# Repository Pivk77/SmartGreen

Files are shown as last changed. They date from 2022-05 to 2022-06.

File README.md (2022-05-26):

# SmartGreen

Smart watering project for your garden. It uses multiple sensors such as ultrasonic depth measurement of your watering tank, humidity sensors, and online weather forecast.

## Usage/Examples

In this repository you are provided with in-detailed schematics of the PCB-board for diy purposes. In the future you might be able to buy the PCB.

The device is meant to be used with [ESPHOME](https://esphome.io/) installed onto and work in conjunction with [HomeAssistant](https://www.home-assistant.io/).

The device uses 12VDC power input. There are 5 230V/16A relays installed onto it so you can connect devices up to 230V (could be less). I've used them as switches for garden pumps and electromagnetic valves.

It also has the built in connector for [SR04M](https://www.google.com/search?q=sr04m) ultrasonic sensor i've used to detect the level of water in a tank.
## Authors

- [@Pivk77](https://github.com/Pivk77)

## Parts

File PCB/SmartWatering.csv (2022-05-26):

Source: | C:\Users\matev\Desktop\SmartWatering\SmartWatering\SmartWatering.kicad_sch
Date: | 24. 05. 2022 16:49:50
Tool: | Eeschema (6.0.5)
Generator: | C:\Program Files\KiCad\6.0\bin\scripting\plugins/bom_csv_grouped_by_value.py
Component Count: | 18
Individual Components:
Item | Qty | Reference(s) | Value | LibPart | Footprint | Datasheet | Spice_Netlist_Enabled | Spice_Primitive
 |  | C1 | 100uF | Device:C_Polarized | Capacitor_THT:CP_Radial_D6.3mm_P2.50mm | ~
 |  | C2 | 10uF | Device:C | Capacitor_SMD:C_0805_2012Metric_Pad1.18x1.45mm_HandSolder | ~
 |  | C3 | 10uF | Device:C | Capacitor_SMD:C_0805_2012Metric_Pad1.18x1.45mm_HandSolder | ~
 |  | C4 | 10uF | Device:C |  | ~
 |  | C5 | 10uF | Device:C |  | ~
 |  | D1 | DIODE | Simulation_SPICE:DIODE | Diode_SMD:D_SMA_Handsoldering | ~ | Y | D
 |  | D2 | LED | Device:LED | LED_SMD:LED_0805_2012Metric_Pad1.15x1.40mm_HandSolder | ~
 |  | J1 | Power_Screw_Terminal | Connector:Screw_Terminal_01x02 | TerminalBlock_Phoenix:TerminalBlock_Phoenix_MPT-0,5-2-2.54_1x02_P2.54mm_Horizontal | ~
 |  | R1 | 12k | Device:R | Resistor_SMD:R_0805_2012Metric_Pad1.20x1.40mm_HandSolder | ~
 |  | R2 | 1k | Device:R | Resistor_SMD:R_0805_2012Metric_Pad1.20x1.40mm_HandSolder | ~
 |  | R3 | 12k | Device:R | Resistor_SMD:R_0805_2012Metric_Pad1.20x1.40mm_HandSolder | ~
 |  | R4 | 12k | Device:R | Resistor_SMD:R_0805_2012Metric_Pad1.20x1.40mm_HandSolder | ~
 |  | R5 | 1k | Device:R | Resistor_SMD:R_0805_2012Metric_Pad1.20x1.40mm_HandSolder | ~
 |  | S1 | Flash_button | Switch:SW_Push |  | ~
 |  | S2 | Reset_button | Switch:SW_Push |  | ~
 |  | U1 | ESP32-WROOM | ESP32-footprints-Shem-Lib:ESP32-WROOM | ESP32-footprints-Lib:ESP32-WROOM
 |  | U2 | L7805 | Regulator_Linear:L7805 | Package_TO_SOT_SMD:TO-263-3_TabPin2 | http://www.st.com/content/ccc/resource/technical/document/datasheet/41/4f/b3/b0/12/d4/47/88/CD00000444.pdf/files/CD00000444.pdf/jcr:content/translations/en.CD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
 |  | U3 | LM3940 | Regulator_Linear:L7805 | Package_TO_SOT_SMD:TO-263-3_TabPin2 | http://www.st.com/content/ccc/resource/technical/document/datasheet/41/4f/b3/b0/12/d4/47/88/CD00000444.pdf/files/CD00000444.pdf/jcr:content/translations/en.CD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
Collated Components:
Item | Qty | Reference(s) | Value | LibPart | Footprint | Datasheet | Spice_Netlist_Enabled | Spice_Primitive
1 | 1 | C1 | 100uF | Device:C_Polarized | Capacitor_THT:CP_Radial_D6.3mm_P2.50mm | ~
2 | 2 | C2, C3 | 10uF | Device:C | Capacitor_SMD:C_0805_2012Metric_Pad1.18x1.45mm_HandSolder | ~
3 | 2 | C4, C5 | 10uF | Device:C |  | ~
4 | 1 | D1 | DIODE | Simulation_SPICE:DIODE | Diode_SMD:D_SMA_Handsoldering | ~ | Y | D
5 | 1 | D2 | LED | Device:LED | LED_SMD:LED_0805_2012Metric_Pad1.15x1.40mm_HandSolder | ~
6 | 1 | J1 | Power_Screw_Terminal | Connector:Screw_Terminal_01x02 | TerminalBlock_Phoenix:TerminalBlock_Phoenix_MPT-0,5-2-2.54_1x02_P2.54mm_Horizontal | ~
7 | 3 | R1, R3, R4 | 12k | Device:R | Resistor_SMD:R_0805_2012Metric_Pad1.20x1.40mm_HandSolder | ~
8 | 2 | R2, R5 | 1k | Device:R | Resistor_SMD:R_0805_2012Metric_Pad1.20x1.40mm_HandSolder | ~
9 | 1 | S1 | Flash_button | Switch:SW_Push |  | ~
10 | 1 | S2 | Reset_button | Switch:SW_Push |  | ~
11 | 1 | U1 | ESP32-WROOM | ESP32-footprints-Shem-Lib:ESP32-WROOM | ESP32-footprints-Lib:ESP32-WROOM
12 | 1 | U2 | L7805 | Regulator_Linear:L7805 | Package_TO_SOT_SMD:TO-263-3_TabPin2 | http://www.st.com/content/ccc/resource/technical/document/datasheet/41/4f/b3/b0/12/d4/47/88/CD00000444.pdf/files/CD00000444.pdf/jcr:content/translations/en.CD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
13 | 1 | U3 | LM3940 | Regulator_Linear:L7805 | Package_TO_SOT_SMD:TO-263-3_TabPin2 | http://www.st.com/content/ccc/resource/technical/document/datasheet/41/4f/b3/b0/12/d4/47/88/CD00000444.pdf/files/CD00000444.pdf/jcr:content/translations/en.CD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

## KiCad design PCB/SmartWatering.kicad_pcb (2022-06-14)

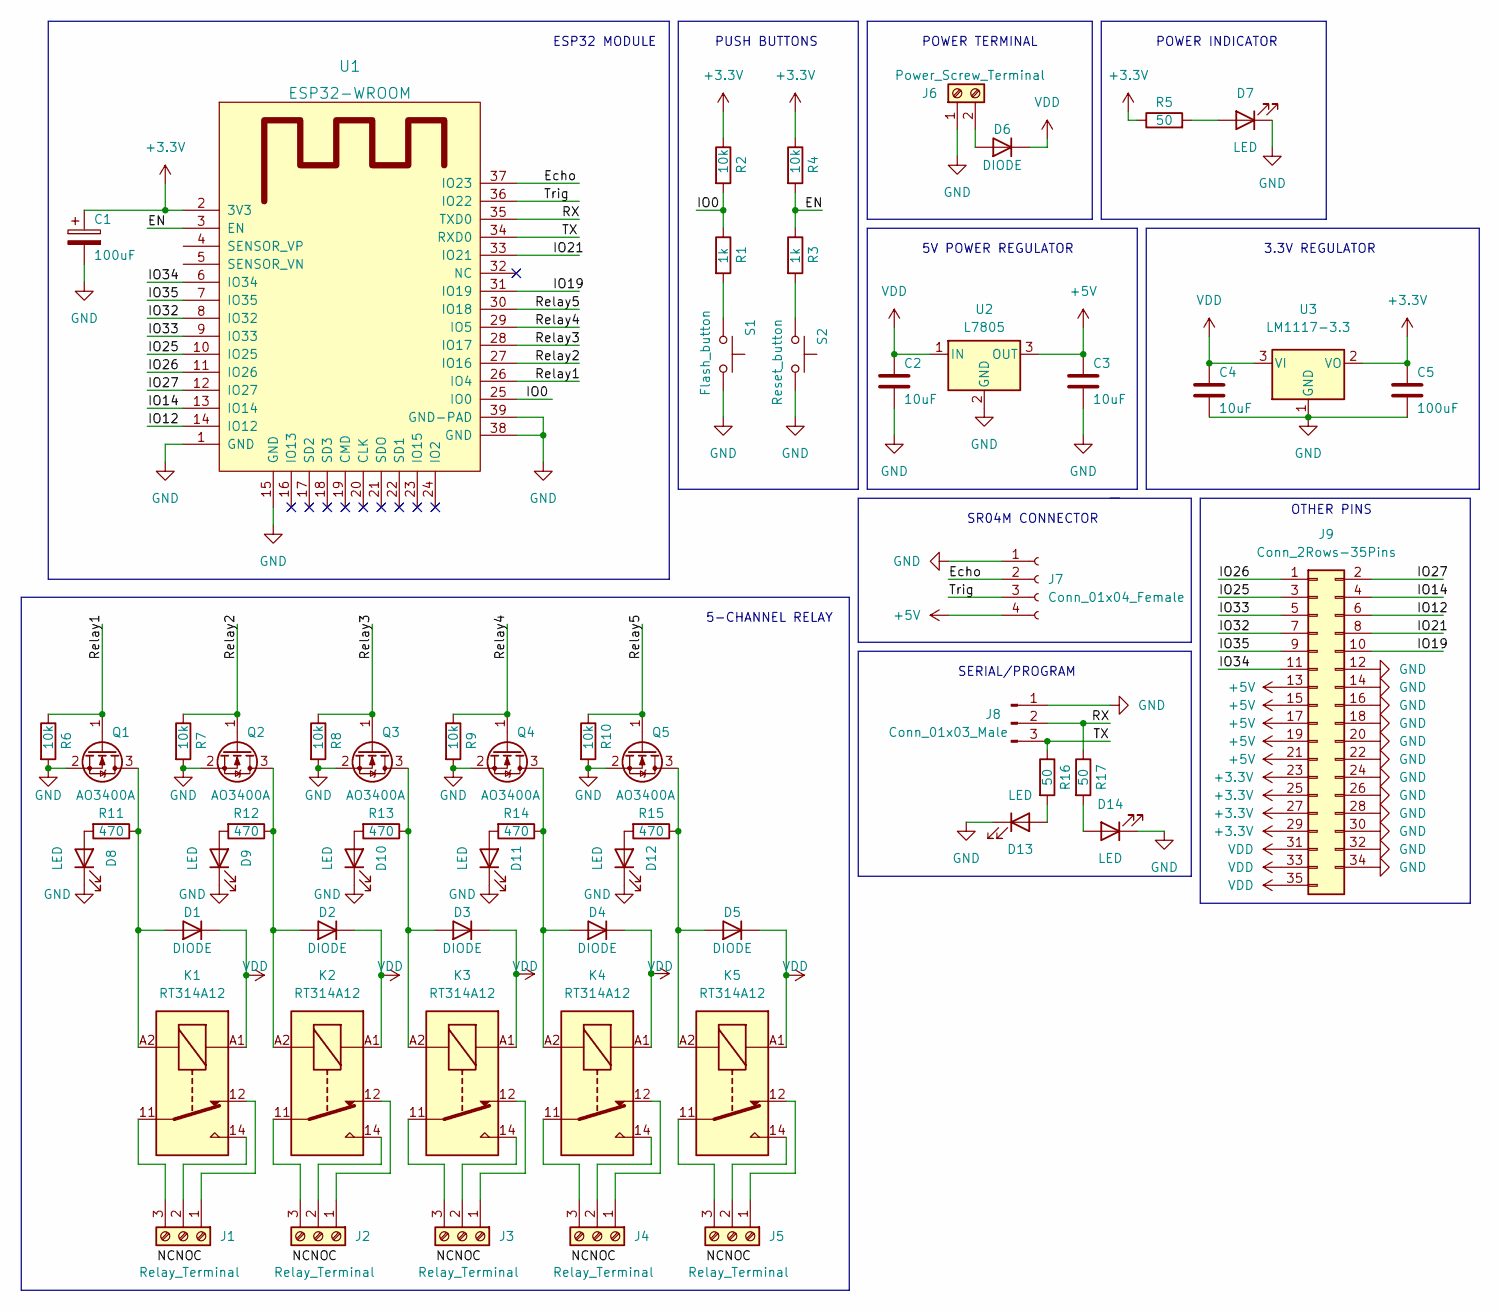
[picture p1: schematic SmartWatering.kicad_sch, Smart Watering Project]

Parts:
C1: 100uF; CP_Radial_D6.3mm_P2.50mm
C2, C3, C4: 10uF; C_0805_2012Metric_Pad1.18x1.45mm_HandSolder
C5: 100uF; C_0805_2012Metric_Pad1.18x1.45mm_HandSolder
D1, D2, D3, D4, D5, D6: DIODE; D_SMA_Handsoldering
D7, D8, D9, D10, D11, D12, D13, D14: LED; LED_0805_2012Metric_Pad1.15x1.40mm_HandSolder
J1, J2, J3, J4, J5: Relay_Terminal; TerminalBlock_Phoenix_MPT-0,5-3-2.54_1x03_P2.54mm_Horizontal
J6: Power_Screw_Terminal; TerminalBlock_Phoenix_MPT-0,5-2-2.54_1x02_P2.54mm_Horizontal
J7: Conn_01x04_Female; PinHeader_1x04_P2.54mm_Vertical
J8: Conn_01x03_Male; PinHeader_1x03_P2.54mm_Vertical
J9: Conn_2Rows-35Pins; PinHeader_2x18_P2.54mm_Vertical
K1, K2, K3, K4, K5: RT314A12; Relay_SPDT_Schrack-RT1-16A-FormC_RM5mm
Q1, Q2, Q3, Q4, Q5: AO3400A; SOT-23
R1, R3: 1k; R_0805_2012Metric_Pad1.20x1.40mm_HandSolder
R2, R4, R6, R7, R8, R9, R10: 10k; R_0805_2012Metric_Pad1.20x1.40mm_HandSolder
R5, R16, R17: 50; R_0805_2012Metric_Pad1.20x1.40mm_HandSolder
R11, R12, R13, R14, R15: 470; R_0805_2012Metric_Pad1.20x1.40mm_HandSolder
S1: Flash_button; SW_SPST_SKQG_WithoutStem
S2: Reset_button; SW_SPST_SKQG_WithoutStem
U1: ESP32-WROOM
U2: L7805; SOT-223-3_TabPin2
U3: LM1117-3.3; SOT-223-3_TabPin2

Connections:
+3V3: C1.1, C5.1, J9.23, J9.25, J9.27, J9.29, R2.1, R4.1, R5.1, U1.2 (3V3), U3.2 (VO)
+5V: C3.1, J7.4, J9.13, J9.15, J9.17, J9.19, J9.21, U2.3 (OUT)
/EN: R3.1, R4.2, U1.3 (EN)
/Echo: J7.2, U1.37 (IO23)
/IO0: R1.1, R2.2, U1.25 (IO0)
/IO12: J9.6, U1.14 (IO12)
/IO14: J9.4, U1.13 (IO14)
/IO19: J9.10, U1.31 (IO19)
/IO21: J9.8, U1.33 (IO21)
/IO25: J9.3, U1.10 (IO25)
/IO26: J9.1, U1.11 (IO26)
/IO27: J9.2, U1.12 (IO27)
/IO32: J9.7, U1.8 (IO32)
/IO33: J9.5, U1.9 (IO33)
/IO34: J9.11, U1.6 (IO34)
/IO35: J9.9, U1.7 (IO35)
/RX: J8.2, R17.1, U1.35 (TXD0)
/Relay1: Q1.1 (G), R6.1, U1.26 (IO4)
/Relay2: Q2.1 (G), R7.1, U1.27 (IO16)
/Relay3: Q3.1 (G), R8.1, U1.28 (IO17)
/Relay4: Q4.1 (G), R9.1, U1.29 (IO5)
/Relay5: Q5.1 (G), R10.1, U1.30 (IO18)
/TX: J8.3, R16.1, U1.34 (RXD0)
/Trig: J7.3, U1.36 (IO22)
GND: C1.2, C2.2, C3.2, C4.2, C5.2, D7.1 (K), D8.1 (K), D9.1 (K), D10.1 (K), D11.1 (K), D12.1 (K), D13.1 (K), D14.1 (K), J6.1, J7.1, J8.1, J9.12, J9.14, J9.16, J9.18, J9.20, J9.22, J9.24, J9.26, J9.28, J9.30, J9.32, J9.34, Q1.2 (S), Q2.2 (S), Q3.2 (S), Q4.2 (S), Q5.2 (S), R6.2, R7.2, R8.2, R9.2, R10.2, S1.2, S2.2, U1.1 (GND), U1.15 (GND), U1.38 (GND), U1.39 (GND-PAD), U2.2 (GND), U3.1 (GND)
unnamed: D1.1 (A), K1.A2, Q1.3 (D), R11.1
unnamed: D2.1 (A), K2.A2, Q2.3 (D), R12.1
unnamed: D3.1 (A), K3.A2, Q3.3 (D), R13.1
unnamed: D4.1 (A), K4.A2, Q4.3 (D), R14.1
unnamed: D5.1 (A), K5.A2, Q5.3 (D), R15.1
unnamed: D6.1 (A), J6.2
unnamed: D7.2 (A), R5.2
unnamed: D8.2 (A), R11.2
unnamed: D9.2 (A), R12.2
unnamed: D10.2 (A), R13.2
unnamed: D11.2 (A), R14.2
unnamed: D12.2 (A), R15.2
unnamed: D13.2 (A), R16.2
unnamed: D14.2 (A), R17.2
unnamed: J1.1, K1.12
unnamed: J1.2, K1.14
unnamed: J1.3, K1.11
unnamed: J2.1, K2.12
unnamed: J2.2, K2.14
unnamed: J2.3, K2.11
unnamed: J3.1, K3.12
unnamed: J3.2, K3.14
unnamed: J3.3, K3.11
unnamed: J4.1, K4.12
unnamed: J4.2, K4.14
unnamed: J4.3, K4.11
unnamed: J5.1, K5.12
unnamed: J5.2, K5.14
unnamed: J5.3, K5.11
unnamed: R1.2, S1.1
unnamed: R3.2, S2.1
VDD: C2.1, C4.1, D1.2 (K), D2.2 (K), D3.2 (K), D4.2 (K), D5.2 (K), D6.2 (K), J9.31, J9.33, J9.35, K1.A1, K2.A1, K3.A1, K4.A1, K5.A1, U2.1 (IN), U3.3 (VI)

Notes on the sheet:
5V POWER REGULATOR
POWER TERMINAL
5-CHANNEL RELAY
POWER INDICATOR
SR04M CONNECTOR
3.3V REGULATOR
SERIAL/PROGRAM
PUSH BUTTONS
OTHER PINS
ESP32 MODULE

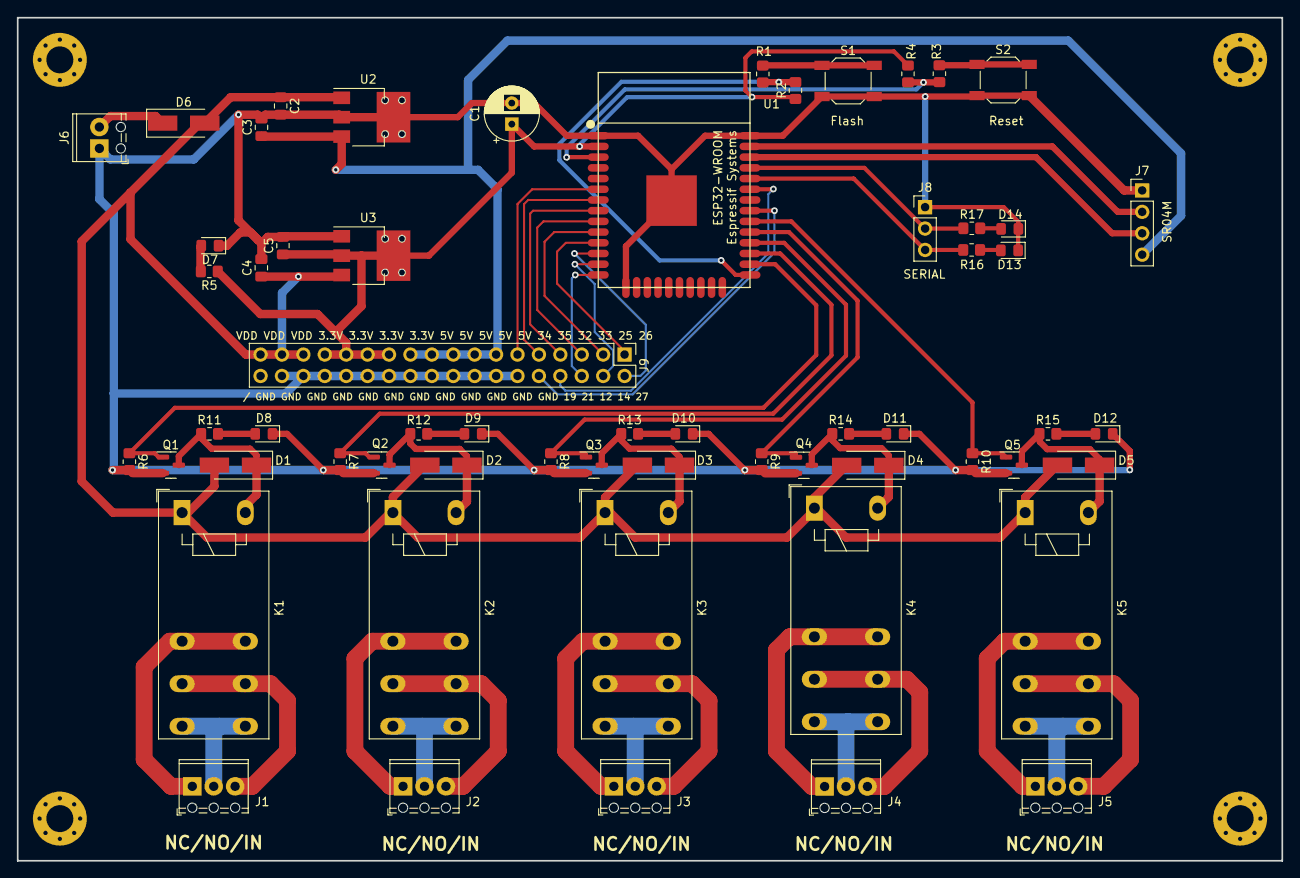
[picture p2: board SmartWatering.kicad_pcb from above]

Board: 2 copper layers, 150.0 x 100.0 mm, 65 parts (1 on the bottom side), 57 nets.

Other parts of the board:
 : MountingHole_3.2mm_M3_Pad_Via
 #2,  #3,  #4: MountingHole_3.2mm_M3_Pad_Via
 #5: LOGO; smartgreen-logo

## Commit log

2022-05-26 Changed github language display
    [SmartWatering.kicad_sch]
2022-05-27 Some changes to the wiring, added connector for other pins currently not in use
2022-05-30 Minor changes
    [SmartWatering.kicad_pcb, SmartWatering.kicad_sch]
2022-06-02 Changed non-used pins on esp external connector
    [SmartWatering.kicad_pcb, SmartWatering.kicad_sch]
2022-06-14 Bug fixes and ready for production
    [SmartWatering-B_ Maska.gbr, SmartWatering-B_ Pasta.gbr, SmartWatering-B_Cu.gbl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]
